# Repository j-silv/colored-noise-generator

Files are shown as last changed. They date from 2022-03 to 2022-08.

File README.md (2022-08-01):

# Colored Noise Generator
A white, pink, and brown noise analog signal generator.

# Schematic
KiCad schematic for the project

# PCB
PCB for the project (top: 3D views in KiCad, bottom: fabricated board)
A single-layer board, DIY-fabricated at my university. Process included copper etching in vertical iron chloride (FeCl3) bath with manual agitation. Adhered to design rules (minimum trace widths, clearances, etc.) as specified by the fabrication technique.

# Simulation
*Coming soon...*

# Results
*Coming soon...*

# Acknowledgements
- Design inspired by [Rod Eliott's pink noise generator](https://sound-au.com/project11.htm)
- Thank you to Denis Muller at the [Physics and Engineering Faculty at the University of Strasbourg](https://physique-ingenierie.unistra.fr/) for helping me fabricate this board

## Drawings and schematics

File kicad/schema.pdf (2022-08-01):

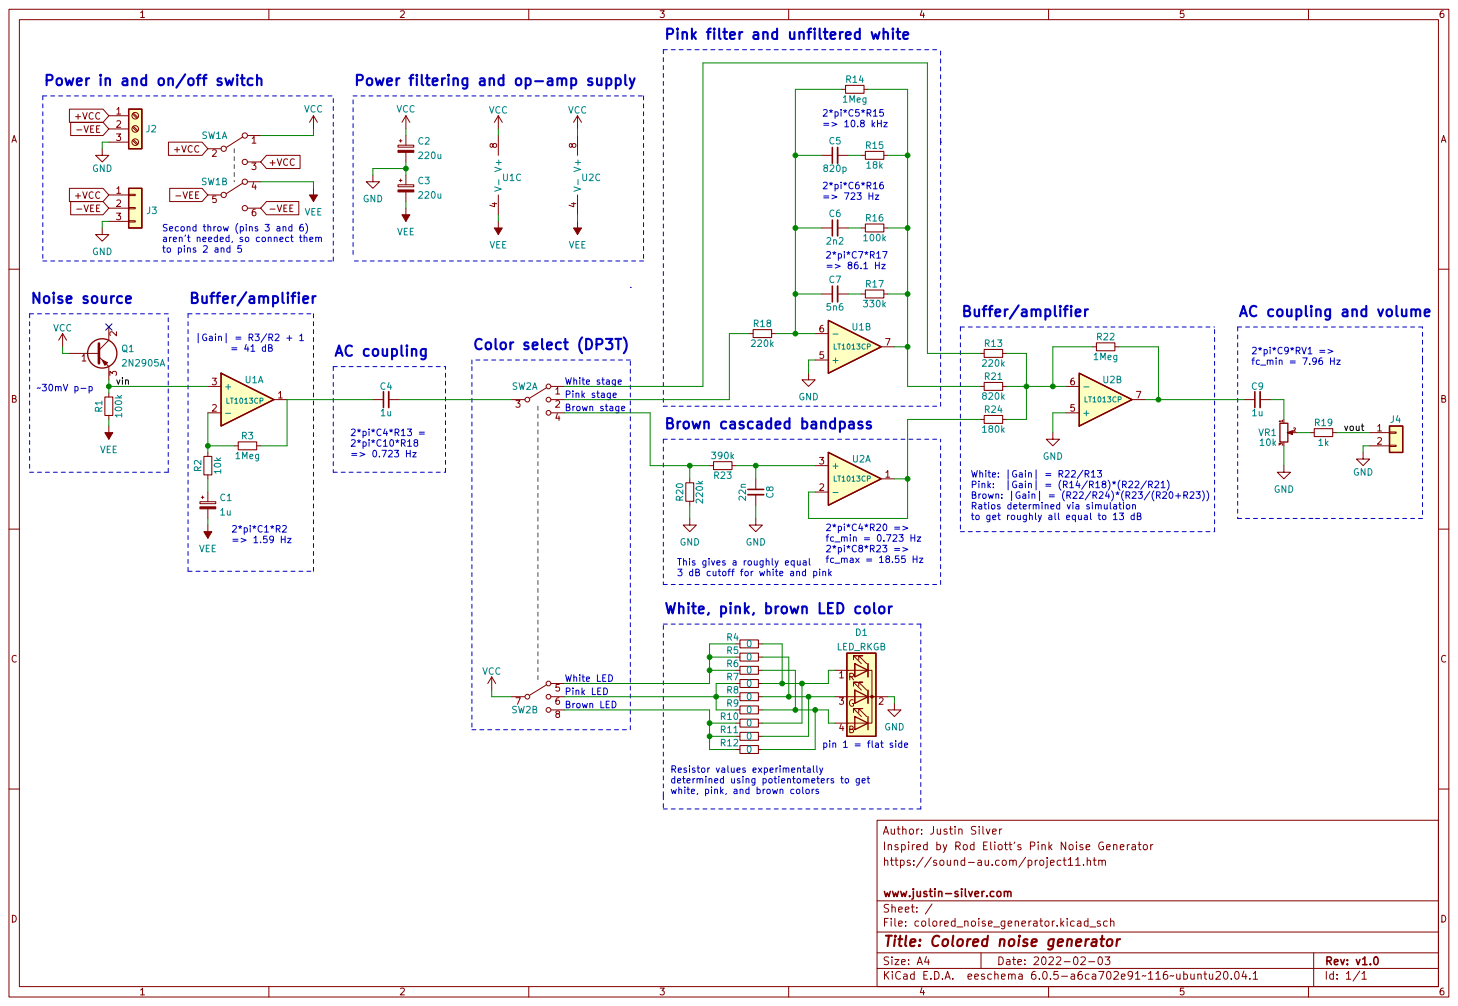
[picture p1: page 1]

Pink filter and unfiltered white

Power in and on/off switch

Power filtering and op-amp supply

Second throw (pins 3 and 6) aren't needed, so connect them
to pins 2 and 5

AC coupling and volume

fc_min = 7.96 Hz Color select (DP3T) White LED AC coupling

Pink LED White stage
Pink stage
Brown stage

White: |Gain| = R22/R13
Pink: |Gain| = (R14/R18)*(R22/R21)
Brown: |Gain| = (R22/R24)*(R23/(R20+R23)) Ratios determined via simulation

Inspired by Rod Eliott's Pink Noise Generator Author: Justin Silver C1

to get roughly all equal to 13 dB

This gives a roughly equal
3 dB cutoff for white and pink

Resistor values experimentally
determined using potientometers to get
white, pink, and brown colors

https://sound-au.com/project11.htm

File: colored_noise_generator.kicad_sch Sheet: / www.justin-silver.com

Id: 1/1 Title: Colored noise generator

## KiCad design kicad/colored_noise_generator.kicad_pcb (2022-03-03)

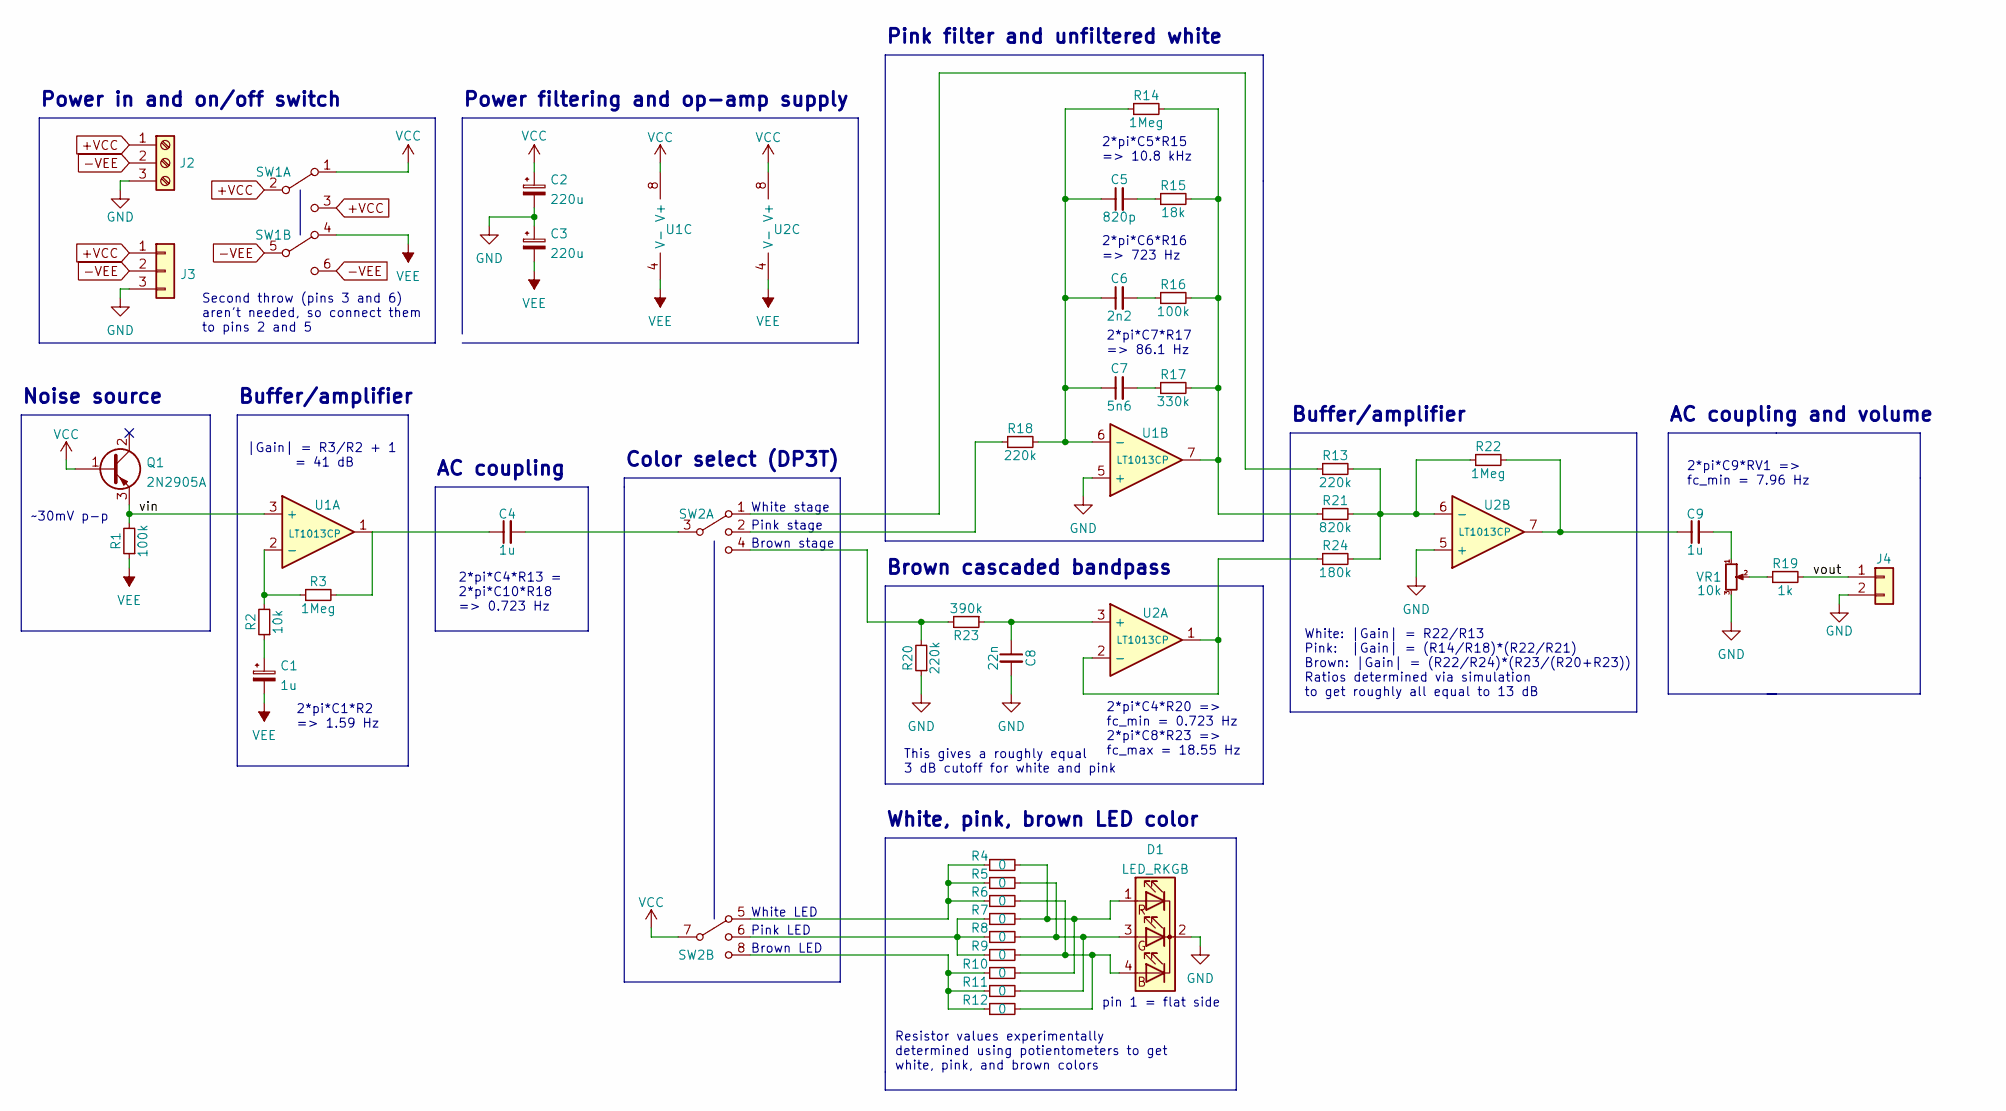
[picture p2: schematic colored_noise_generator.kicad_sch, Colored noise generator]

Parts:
C1: 1u; CP_Axial_L10.0mm_D6.0mm_P15.00mm_Horizontal
C2, C3: 220u; CP_Axial_L18.0mm_D8.0mm_P25.00mm_Horizontal
C4, C9: 1u; C_Rect_L7.0mm_W6.0mm_P5.00mm
C5: 820p; C_Disc_D4.7mm_W2.5mm_P5.00mm
C6: 2n2; C_Rect_L7.2mm_W2.5mm_P5.00mm_FKS2_FKP2_MKS2_MKP2
C7: 5n6; C_Rect_L7.2mm_W2.5mm_P5.00mm_FKS2_FKP2_MKS2_MKP2
C8: 22n; C_Rect_L7.2mm_W2.5mm_P5.00mm_FKS2_FKP2_MKS2_MKP2
D1: LED_RKGB; LED_D5.0mm-4_RGB
J2: Screw_Terminal_01x03; screw_terminal_1x3
J3: Conn_01x03; PinHeader_1x03_P2.54mm_Vertical
J4: Conn_01x02; PinHeader_1x02_P2.54mm_Vertical
Q1: 2N2905A; 2N2905A-TO-39
R1, R16: 100k; R_Axial_DIN0207_L6.3mm_D2.5mm_P7.62mm_Horizontal
R2: 10k; R_Axial_DIN0207_L6.3mm_D2.5mm_P7.62mm_Horizontal
R3, R14, R22: 1Meg; R_Axial_DIN0207_L6.3mm_D2.5mm_P7.62mm_Horizontal
R4, R5, R6, R7, R8, R9, R10, R11, R12: 0; R_Axial_DIN0207_L6.3mm_D2.5mm_P7.62mm_Horizontal
R13, R18, R20: 220k; R_Axial_DIN0207_L6.3mm_D2.5mm_P7.62mm_Horizontal
R15: 18k; R_Axial_DIN0207_L6.3mm_D2.5mm_P7.62mm_Horizontal
R17: 330k; R_Axial_DIN0207_L6.3mm_D2.5mm_P7.62mm_Horizontal
R19: 1k; R_Axial_DIN0207_L6.3mm_D2.5mm_P7.62mm_Horizontal
R21: 820k; R_Axial_DIN0207_L6.3mm_D2.5mm_P7.62mm_Horizontal
R23: 390k; R_Axial_DIN0207_L6.3mm_D2.5mm_P7.62mm_Horizontal
R24: 180k; R_Axial_DIN0207_L6.3mm_D2.5mm_P7.62mm_Horizontal
SW1: DPDT; dpdt
SW2: DP3T; dp3t
U1, U2: LT1013CP; DIP-8_W7.62mm_Socket
VR1: 10k; elegoo_pot

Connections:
+VCC: J2.1, J3.1, SW1.2 (B), SW1.3 (C)
-VEE: J2.2, J3.2, SW1.5 (B), SW1.6 (C)
/vin: Q1.3 (E), R1.2, U1.3 (+)
/vout: J4.1, R19.2
GND: C2.2, C3.1, C8.2, D1.2 (K), J2.3, J3.3, J4.2, R20.1, U1.5 (+), U2.5 (+), VR1.3
unnamed: C1.1, R2.1
unnamed: C4.1, R3.2, U1.1
unnamed: C4.2, SW2.3
unnamed: C5.1, C6.1, C7.1, R14.1, R18.2, U1.6 (-)
unnamed: C5.2, R15.1
unnamed: C6.2, R16.1
unnamed: C7.2, R17.1
unnamed: C8.1, R23.1, U2.3 (+)
unnamed: C9.1, R22.2, U2.7
unnamed: C9.2, VR1.1
unnamed: D1.1 (RA), R4.2, R7.2, R10.2
unnamed: D1.3 (GA), R5.2, R8.2, R11.2
unnamed: D1.4 (BA), R6.2, R9.2, R12.2
unnamed: R2.2, R3.1, U1.2 (-)
unnamed: R4.1, R5.1, R6.1, SW2.5
unnamed: R7.1, R8.1, R9.1, SW2.6
unnamed: R10.1, R11.1, R12.1, SW2.8
unnamed: R13.1, SW2.1
unnamed: R13.2, R21.2, R22.1, R24.2, U2.6 (-)
unnamed: R14.2, R15.2, R16.2, R17.2, R21.1, U1.7
unnamed: R18.1, SW2.2
unnamed: R19.1, VR1.2
unnamed: R20.2, R23.2, SW2.4
unnamed: R24.1, U2.1, U2.2 (-)
VCC: C2.1, Q1.1 (B), SW1.1 (A), SW2.7, U1.8 (V+), U2.8 (V+)
VEE: C1.2, C3.2, R1.1, SW1.4 (A), U1.4 (V-), U2.4 (V-)

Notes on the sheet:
Color select (DP3T)
~30mV p-p
2*pi*C4*R20 => fc_min = 0.723 Hz 2*pi*C8*R23 => fc_max = 18.55 Hz
Resistor values experimentally determined using potientometers to get white, pink, and brown colors
pin 1 = flat side
White, pink, brown LED color
Power in and on/off switch
Buffer/amplifier
Brown LED
2*pi*C6*R16 => 723 Hz
2*pi*C9*RV1 => fc_min = 7.96 Hz
Noise source
Pink filter and unfiltered white
Pink LED
|Gain| = R3/R2 + 1 = 41 dB
2*pi*C5*R15 => 10.8 kHz
2*pi*C7*R17 => 86.1 Hz
Pink stage
2*pi*C1*R2 => 1.59 Hz
2*pi*C4*R13 = 2*pi*C10*R18 => 0.723 Hz
White LED
Brown stage
Second throw (pins 3 and 6) aren't needed, so connect them to pins 2 and 5
White stage
White: |Gain| = R22/R13 Pink: |Gain| = (R14/R18)*(R22/R21) Brown: |Gain| = (R22/R24)*(R23/(R20+R23)) Ratios determined via simulation to get roughly all equal to 13 dB
Brown cascaded bandpass
AC coupling and volume
Power filtering and op-amp supply
AC coupling
This gives a roughly equal 3 dB cutoff for white and pink

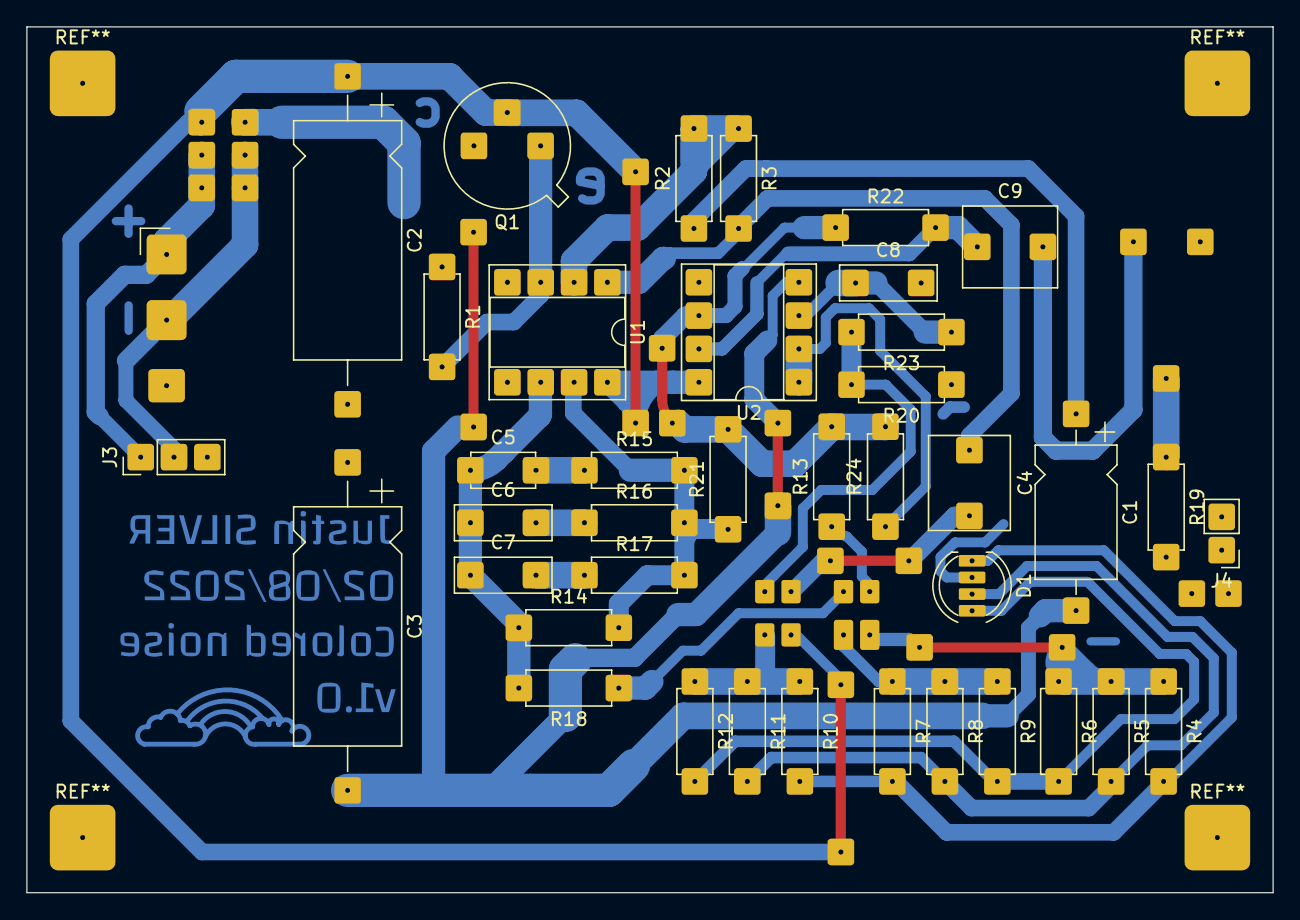
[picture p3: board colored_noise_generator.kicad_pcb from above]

Board: 2 copper layers, 95.0 x 66.0 mm, 43 parts (0 on the bottom side), 31 nets.

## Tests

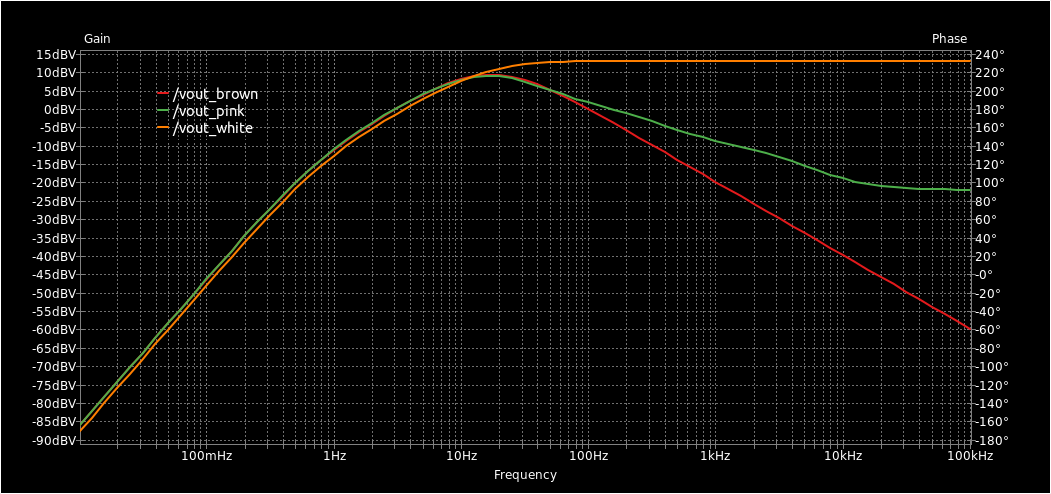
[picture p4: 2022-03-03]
kicad/sim/sim_results.png

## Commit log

2022-02-16 Initial commit with design files
    [colored_noise_generator.kicad_pcb, colored_noise_generator.kicad_sch, colored_noise_generator_SIM.kicad_sch]
2022-02-16 Increase pour clearance, copper pour to board edges
    Increase ground plane to trace clearance. Also add separate
    copper pour rectangles to fill to board's perimeter.
    Needed to add copper pours around graphic text with
    different clearance rules.
    [colored_noise_generator.kicad_pcb]
2022-02-19 Add photos after board fabrication
2022-03-03 Change component values while referring to simulation results
    [colored_noise_generator.kicad_pcb, colored_noise_generator.kicad_sch, colored_noise_generator_sim.kicad_sch]
2022-08-01 Update README with images/more info and add schematic
2022-08-01 Reduce size of linked PCB images to make GitHub happy
    Apparently when linking photos via the README, there is
    a 5 MB file size limit.
2022-08-01 Remove fab outputs
    No need to include these as they can be easily regenerated from KiCad.
    Plus the files were slightly outdated.
